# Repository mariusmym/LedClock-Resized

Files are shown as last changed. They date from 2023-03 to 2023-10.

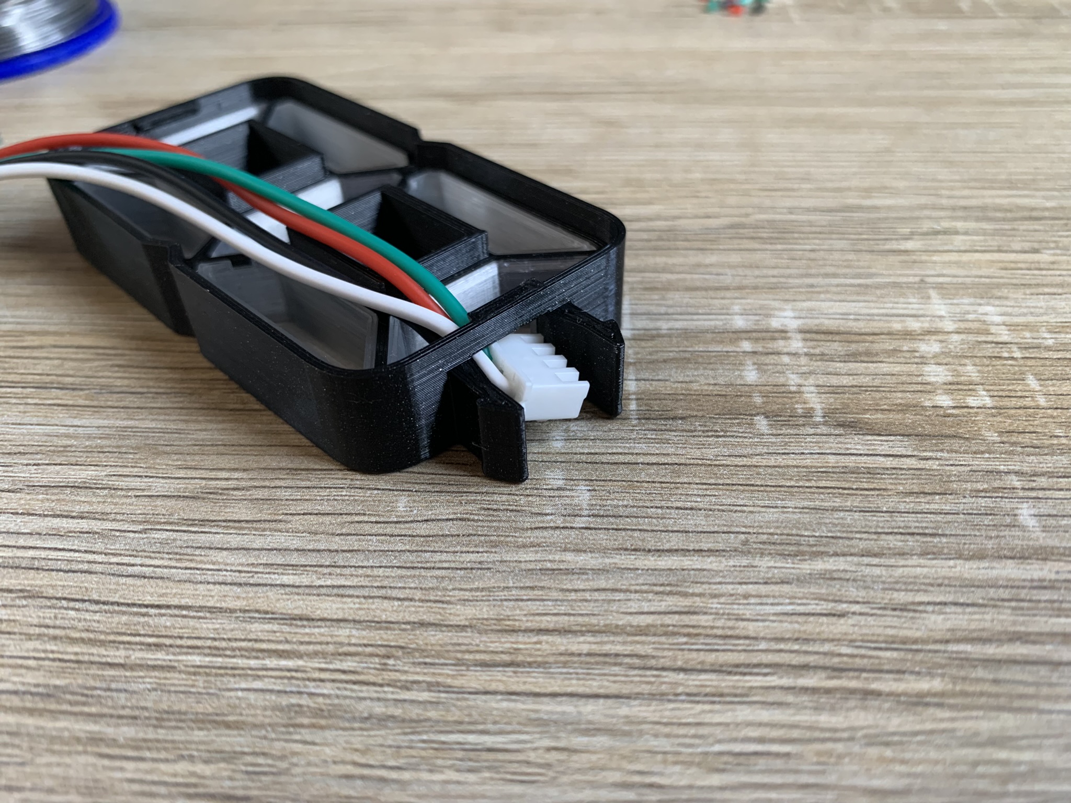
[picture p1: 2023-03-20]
LedClock-Resized2-40x66mm/Images/IMG_2581.jpeg

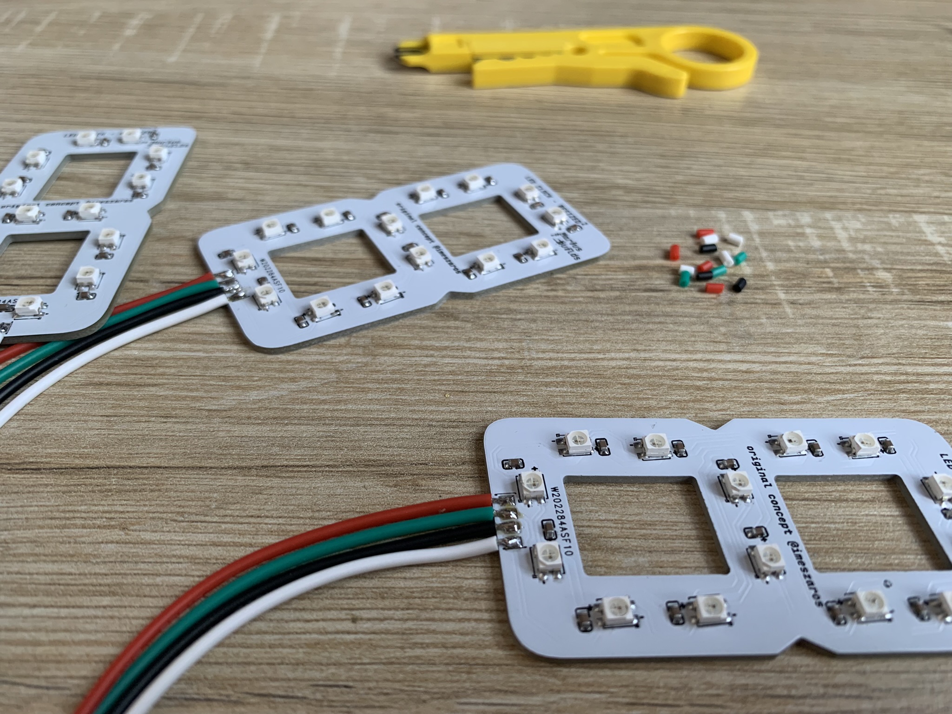
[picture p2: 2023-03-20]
LedClock-Resized2-40x66mm/Images/IMG_2576.jpeg

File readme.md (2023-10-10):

LED Clock

<p align="center">
  
  
  
  
</p>

# LedClock-Resized

## About

As its name tells, this is a resized and an easier to make/print version of [ledclock project](https://github.com/imeszaros/ledclock), powered by [WLED](https://github.com/Aircoookie/WLED). 

**There are TWO resized dimensions available:** 
  1. **52x92mm digits version** : [see folder](https://github.com/mariusmym/LedClock-Resized/tree/master/LedClock_Resized)
  2. **40x66mm digits version** : [see folder](https://github.com/mariusmym/LedClock-Resized/tree/master/LedClock-Resized2-40x66mm)
  
**Keep in mind that dimensions mentioned above represents only the height of the PCB digits. The base is not included. Height of the base is the same.**
  
IMG_3209 copy

This fork is intended just to share the Gerbers and 3D files I used for this remix. If you need more detailed informations, please read descriptions and assembly guide from the [original repository](https://github.com/imeszaros/ledclock).
[imeszaros](https://github.com/imeszaros) did an oustanding job in providing all the explanations required. 

## Main differences

- all PCBs are under 100mm height so you can order them for like $5 + shipping from [PCBWay.com](https://www.pcbway.com/) .
You can also order them directly from [my PCBWay profile](https://www.pcbway.com/project/member/?bmbno=1D9FACD8-0C52-4C) you can download the gerber files and send them to your manufacturer. 
- 3D printed parts can be printed on smaller printers because the base is split in half (you have to assemble it with some M3 screws and nuts). I printed my parts on an Ender3 V2, so I guess anyone can print them.
- 3D printed parts can be printed without supports. Please check 3mf folder to see orientation if you can't figure it out.
- controller board, led 7segments and dots now uses only 0805 SMD components for easier soldering. I don't have a reflow hot-plate so I made the assembly by hand.
- controller board now uses an **ESP32 D1 Mini** [link for reference](https://www.aliexpress.com/item/1005003746817278.html) for more convenience. By using an embedded ESP32 you will have to overcomplicate the board. Another reason for using a dedicated ESP32 D1 Mini is because some of the components required in the original design are impossible to solder by hand (CP2102). I
f you want, **you can use the original controller board design**, is fully compatible with **LedClock-Resized**.

## Firmware

Firmware is provided by the awesome work of [imeszaros](https://github.com/imeszaros). 
Just connect the ESP32 Mini onto the computer (be sure you have drivers installed for your board USB-TTL chip) and use [this tool](https://imeszaros.github.io/ledclock/) for initial flash. Then plug the ESP32 board it into the main controller board.

## Assembly

Assembly of this project is pretty straightforward: 
- order the PCBs and solder them

28373dad-76af-430c-a674-46bc3df38653



IMG_2576s

- print the 3D required parts and assemble them (use 4 x M3x20mm screws and nuts to join the base of the 52x92mm version)

IMG_3756s

d58b3460-f934-42f0-a672-9b96344d7cfe

- flash the firmware on the ESP32 Mini and then connect it to the controller board.

IMG_4004s

- join the PCBs with the 3D printed parts

IMG_2581s

d932719f-d477-4b1a-8fd8-3f6773710fba

IMG_1876s

IMG_4681ss

- **provide 5V 2A power supply with  2.5mm x 5.85mm barrel jack connector.** 
- make your settings in the WLED APP. Use [this guide](https://github.com/imeszaros/ledclock/blob/master/ledclock/users-guide.md) if you're not familiarized with WLED App.

## ENJOY !



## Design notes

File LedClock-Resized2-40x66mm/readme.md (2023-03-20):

## LedClock-Resized 40x66 mm version

### Files for the 40x66mm digits version of LedClock-Resized. Please see folders above.

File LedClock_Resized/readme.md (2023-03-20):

## LedClock-Resized 52x92 mm version

### Files for the 52x92mm digits version of LedClock-Resized. Please see folders above.

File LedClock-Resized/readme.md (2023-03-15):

# LedClock-Resized

## About

As its name tells, this is a resized and an easier to make version of ledclock project.

Main differences are:

- all PCBs are under 100mm height so you can order them for like $5 + shipping from [PCBWay.com](https://www.pcbway.com/) .
You can also order them directly from [my PCBWay profile](https://www.pcbway.com/project/member/?bmbno=1D9FACD8-0C52-4C) you can download the gerber files and send them to your manufacturer. 
- 3D printed parts can be printed on smaller printers because the base is split in half (you have to assemble it with some M3 screws and nuts). I printed my parts on an Ender3 V2, so I guess anyone can print them.
- 3D printed parts can be printed without supports. Please check 3mf folder to see orientation if you can't figure it out.
- controller board, led 7segments and dots now uses only 0805 SMD components for easier soldering. I don't have a reflow hot-plate so I made the assembly by hand.
- controller board now uses an **ESP32 D1 Mini** [link for reference](https://www.aliexpress.com/item/1005003746817278.html) for more convenience. By using an embedded ESP32 you will have to overcomplicate the board. Another reason for using a dedicated ESP32 D1 Mini is because some of the components required in the original design are impossible to solder by hand (CP2102). 

## Firmware

Firmware is provided by the awesome work of [@imeszaros](https://github.com/imeszaros). 
Just connect the ESP32 Mini onto the computer (be sure you have drivers installed for CHxxxx or CPxxxx chip) and use [this awesome tool](https://imeszaros.github.io/ledclock/) for initial flash. Then plug the ESP32 it into the main controller board

## Assembly

Assembly of this project is pretty straightforward: 
- order the PCBs and solder them

28373dad-76af-430c-a674-46bc3df38653



- print the 3D required parts and assemble them (use 4 x M3x20mm screws and nuts to join the base)

IMG_3756s

d58b3460-f934-42f0-a672-9b96344d7cfe

- flash the firmware on the ESP32 Mini and then connect it to the controller board.

IMG_4004s

- join the PCBs with the 3D printed parts

d932719f-d477-4b1a-8fd8-3f6773710fba

IMG_1876s

- **provide 5V 2A power supply with  2.5mm x 5.85mm barrel jack connector.** 
- make your settings in the WLED APP. Use [this guide](https://github.com/imeszaros/ledclock/blob/master/ledclock/users-guide.md) if you're not familiarized with WLED App.

## ENJOY !

34732020s

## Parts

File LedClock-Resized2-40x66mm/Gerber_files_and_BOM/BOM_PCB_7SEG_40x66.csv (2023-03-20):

ID | Name | Designator | Footprint | Quantity | Manufacturer Part | Manufacturer | Supplier | Supplier Part | Price
1 | WS2812B-MINI | 1,2,3,4,5,6,7,8,9,10,11,12,13,14 | LED-SMD_4P-L3.5-W3.5-TL_WS2812B | 14 | WS2812B-Mini | worldsemi | LCSC | C527089 | 0.016
2 | 100nF | C1,C2,C3,C4,C5,C6,C7,C8,C9,C10,C11,C12,C13,C14 | C0603 | 14 | C0603C104K5RACAUTO | KEMET(基美) | LCSC | C129621 | 0.002
3 | HDR-M-2.54_1x4 | J1 | H1X4_SMD_SMALL | 1 |  |  | LCSC | C124378 | 0.007

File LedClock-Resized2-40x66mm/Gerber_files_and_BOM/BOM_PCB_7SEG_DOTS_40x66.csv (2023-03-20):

ID | Name | Designator | Footprint | Quantity | Manufacturer Part | Manufacturer | Supplier | Supplier Part | Price
1 | 100nF | C1,C2 | C0603 | 2 | C0603C104K5RACAUTO | KEMET(基美) | LCSC | C129621 | 0.002
2 | WS2812B-MINI | 1,2 | LED-SMD_4P-L3.5-W3.5-TL_WS2812B | 2 | WS2812B-Mini | worldsemi | LCSC | C527089 | 0.016
3 | HDR-M-2.54_1x4 | J1 | H1X4_SMD_SMALL | 1 |  |  | LCSC | C124378 | 0.007

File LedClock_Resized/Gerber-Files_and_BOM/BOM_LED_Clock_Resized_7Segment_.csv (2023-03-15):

ID | Name | Designator | Footprint | Quantity | Manufacturer Part | Manufacturer | Supplier | Supplier Part | Price
1 | HDR-M-2.54_1x4 | J1 | H2X2_SMD | 1 |  |  | LCSC | C124378 | 0.007
2 | WS2812B | U1,U2,U3,U4,U5,U6,U7,U8,U9,U10,U11,U12,U13,U14 | LED-SMD_4P-L5.0-W5.0-TL | 14 | WS2812B | Worldsemi | LCSC | C114585
3 | 100nF | C1,C2,C3,C4,C5,C6,C7,C8,C9,C10,C11,C12,C13,C14 | C0805 | 14 | CC0805KRX7R9BB104 | YAGEO(国巨) | LCSC | C49678 | 0.001

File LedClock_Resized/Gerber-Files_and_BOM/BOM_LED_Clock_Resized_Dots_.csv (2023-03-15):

ID | Name | Designator | Footprint | Quantity | Manufacturer Part | Manufacturer | Supplier | Supplier Part | Price
1 | 100nF | C1,C2 | C0805 | 2 | CC0805KRX7R9BB104 | YAGEO(国巨) | LCSC | C49678 | 0.001
2 | WS2812B | U2,U1 | LED-SMD_4P-L5.0-W5.0-TL | 2 | WS2812B | Worldsemi | LCSC | C114585
3 | HDR-M-2.54_1x4 | J1 | H2X2_SMD | 1 |  |  | LCSC | C124378 | 0.007

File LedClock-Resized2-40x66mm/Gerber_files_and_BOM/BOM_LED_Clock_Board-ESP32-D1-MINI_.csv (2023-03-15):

ID | Name | Designator | Footprint | Quantity | Manufacturer Part | Manufacturer | Supplier | Supplier Part | Price
1 | 50kΩ | R4 | RES-ADJ-SMD_3314G-1-103E | 1 | 3314G-1-503E | BOURNS | LCSC | C719184 | 0.085
2 | 470uF | C1 | CAP-SMD_BD6.3-L6.6-W6.6-FD | 1 | RVT0J471M0607 | HONOR(荣誉) | LCSC | C3354 | 0.008
3 | HX25003-4WAP | CN3,CN1,CN2,CN4,CN5 | CONN-TH_4P-P2.50_HX25003-4WAP | 5 | HX25003-4WAP | HX(Zhejiang Yueqing Hongxing Elec) | LCSC | C442328 | 0.004
4 | 100 | R1 | R0805 | 1 | AC0805FR-07100RL | YAGEO(国巨) | LCSC | C138274 | 0.001
5 | 10K | R2,R3 | R0805 | 2 | AC0805FR-0710KL | YAGEO(国巨) | LCSC | C140868 | 0.001
6 | BUZZER | SG1 | DIP-BUZZER-12X9.5 | 1
7 | DC-005I-5A-2.5 | DC1 | DC-IN-TH_DC-005I-5A-2.5 | 1 | DC-005I-5A-2.5 | XKB Connectivity(中国星坤) | LCSC | C2689704 | 0.083
8 | TEPT5700 | Q3 | TEPT5700 | 1 | TEPT5700 | VISHAY | LCSC | C141763 | 0.089
9 | BSS138 | Q4 | SOT-23-3_L2.9-W1.3-P1.90-LS2.4-BR | 1 | BSS138 | CJ | LCSC | C78284 | 0.004

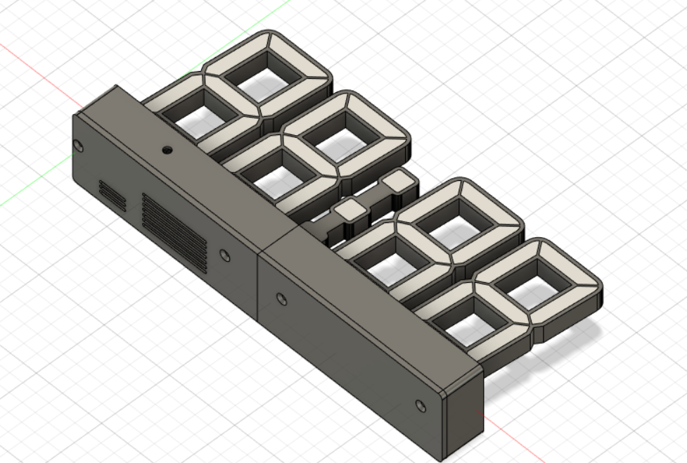
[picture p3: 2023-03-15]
LedClock_Resized/CAD files/Led-Clock-Resized(2PartsBase)-f3z.png

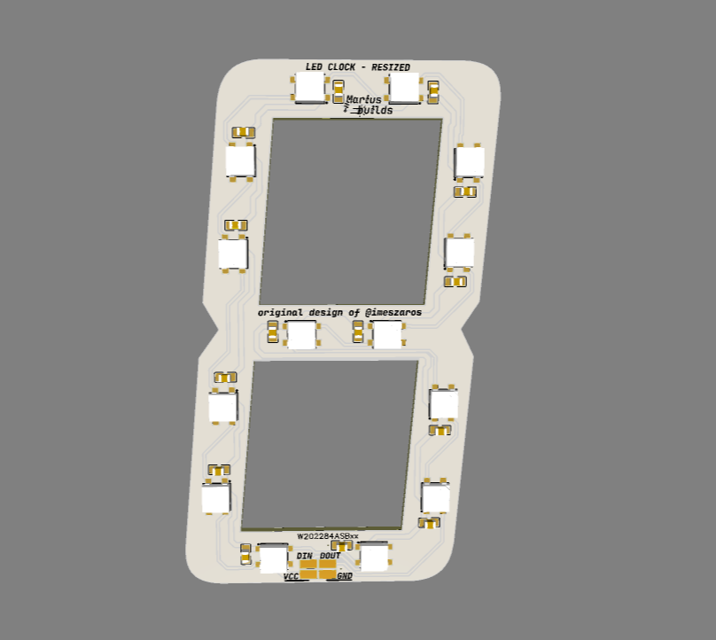
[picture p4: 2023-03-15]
LedClock_Resized/Gerber-Files_and_BOM/LED_Clock_Resized_7Segment_1.png

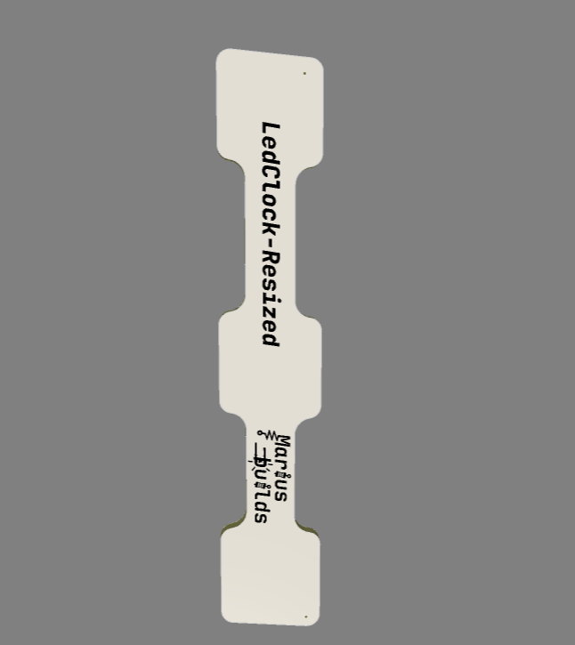
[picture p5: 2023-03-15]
LedClock_Resized/Gerber-Files_and_BOM/LED_Clock_Resized_Dots_2.png

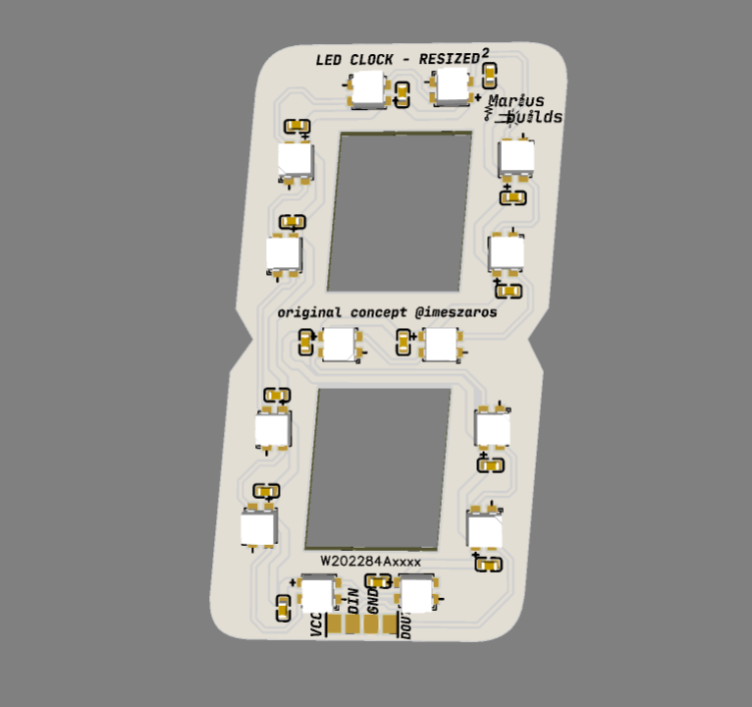
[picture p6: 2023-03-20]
LedClock-Resized2-40x66mm/Gerber_files_and_BOM/7SEG_40X66_1.png

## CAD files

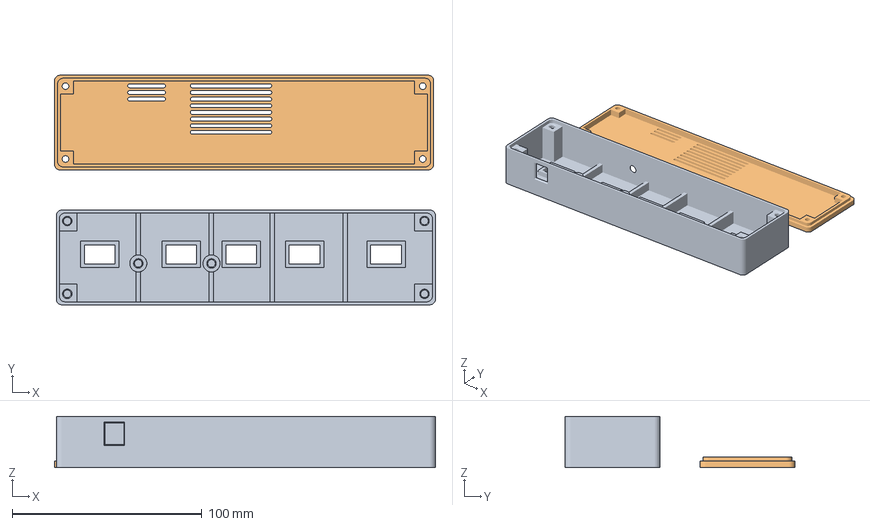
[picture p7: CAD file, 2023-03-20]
LedClock-Resized2-40x66mm/3D_printing_files/3mf_files/BASE_Body&Lid.3mf
200.9 x 121.1 x 27.0 mm
BaseBody.stl
LidBody.stl

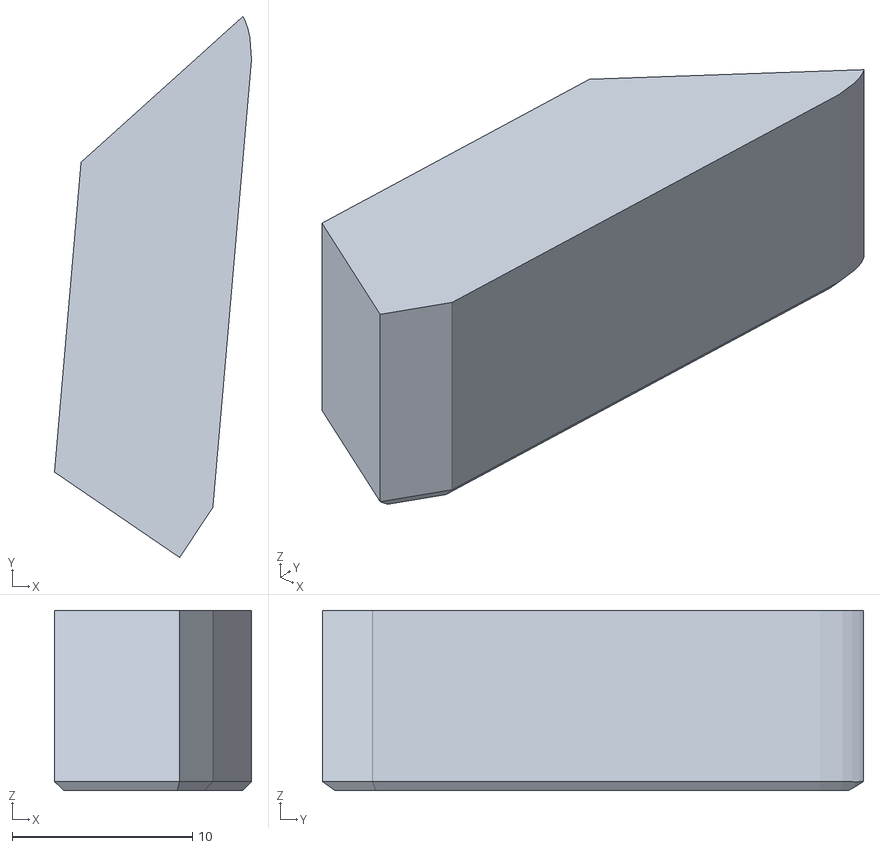
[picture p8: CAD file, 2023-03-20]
LedClock-Resized2-40x66mm/3D_printing_files/STL_files/7SEG_40x66/SegCovBody3.stl
10.9 x 30.0 x 10.0

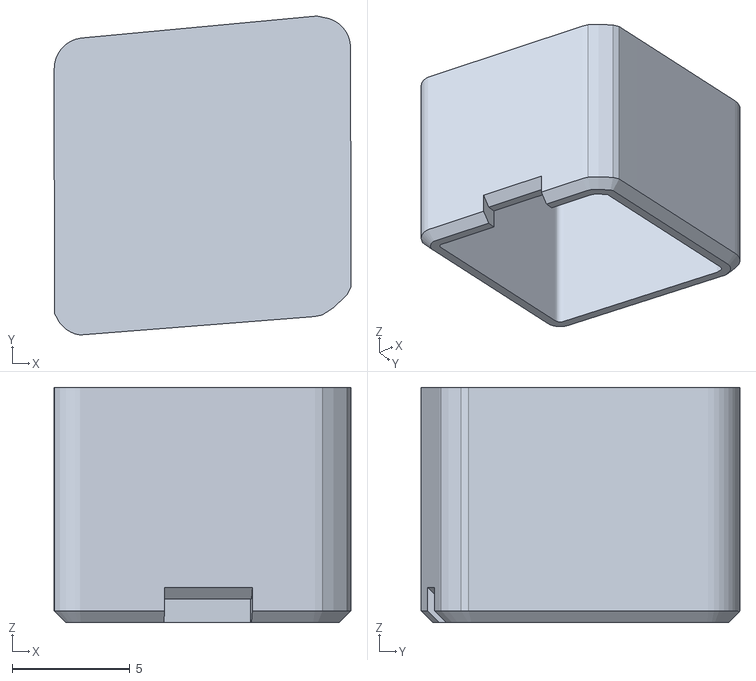
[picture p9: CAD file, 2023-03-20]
LedClock-Resized2-40x66mm/3D_printing_files/STL_files/7SEG_DOTS_40x66/DotsCover1.stl
12.6 x 13.6 x 10.0

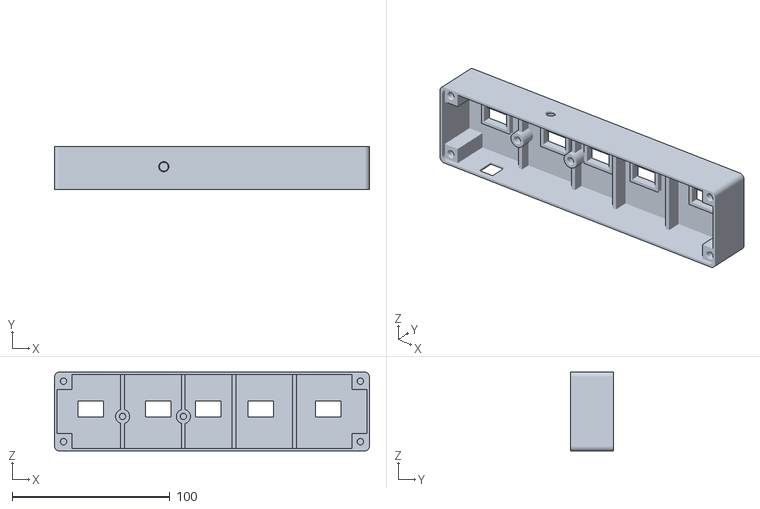
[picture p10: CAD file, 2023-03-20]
LedClock-Resized2-40x66mm/3D_printing_files/STL_files/BASE_FOR_40x66/BaseBody.stl
200.0 x 27.0 x 50.0

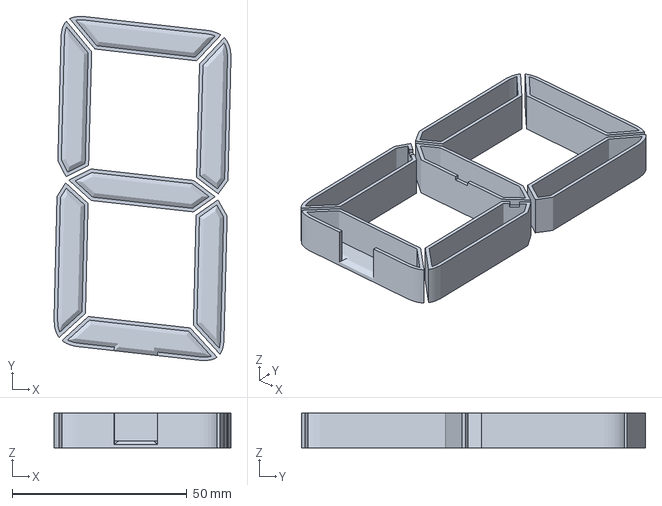
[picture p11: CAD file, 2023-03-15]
LedClock_Resized/3D-print/3mf-files/CE3_SegmentCovers-ALL.3mf
50.6 x 98.4 x 10.0 mm

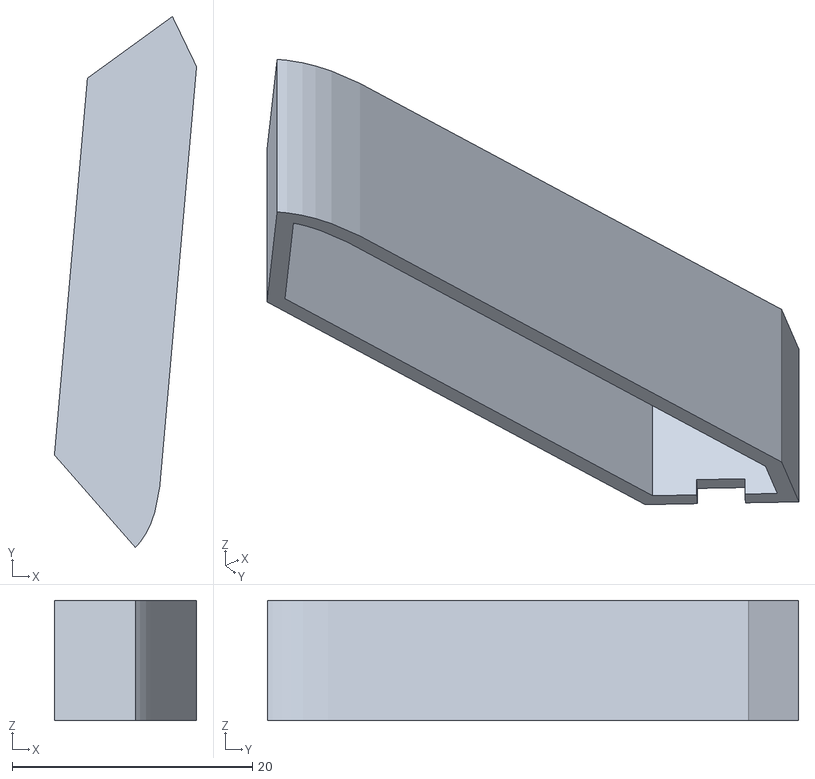
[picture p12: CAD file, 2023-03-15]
LedClock_Resized/3D-print/stl-files/SegmentCover-BottomRight.stl
11.8 x 44.2 x 10.0

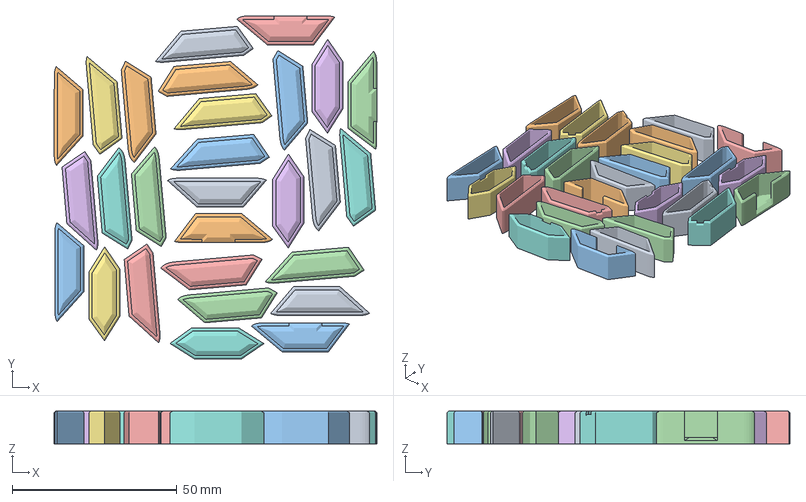
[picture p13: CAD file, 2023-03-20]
LedClock-Resized2-40x66mm/3D_printing_files/3mf_files/7SEG_LED_COVERS.3mf
98.0 x 104.2 x 10.0 mm
SegCovBody1.stl
SegCovBody2.stl
SegCovBody3.stl
SegCovBody4.stl
SegCovBody5.stl
SegCovBody6.stl
SegCovBody7.stl
SegCovBody5.stl(1)
SegCovBody5.stl(2)
SegCovBody5.stl(3)
SegCovBody2.stl(1)
SegCovBody2.stl(2)
SegCovBody2.stl(3)
SegCovBody6.stl(1)
SegCovBody6.stl(2)
SegCovBody6.stl(3)
SegCovBody1.stl(1)
SegCovBody1.stl(2)
SegCovBody1.stl(3)
SegCovBody3.stl(1)
SegCovBody3.stl(2)
SegCovBody3.stl(3)
SegCovBody7.stl(1)
SegCovBody7.stl(2)
SegCovBody7.stl(3)
SegCovBody4.stl(1)
SegCovBody4.stl(2)
SegCovBody4.stl(3)

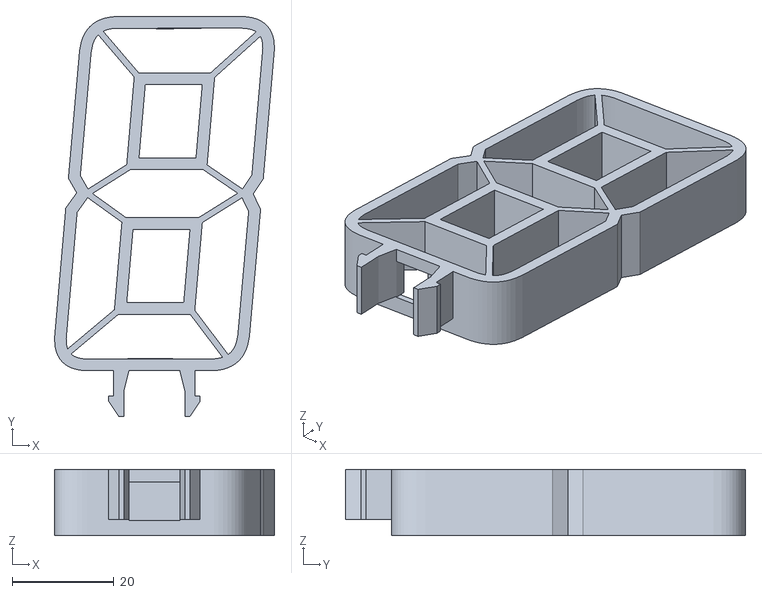
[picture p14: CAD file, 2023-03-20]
LedClock-Resized2-40x66mm/3D_printing_files/STL_files/7SEG_40x66/Case.stl
43.2 x 78.6 x 13.0

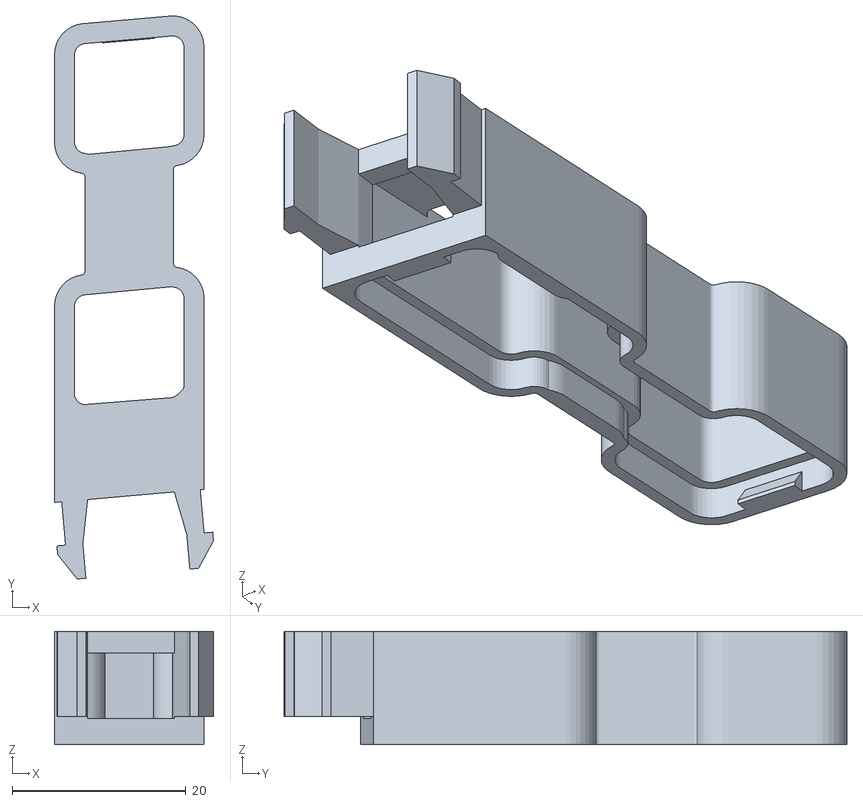
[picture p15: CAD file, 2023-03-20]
LedClock-Resized2-40x66mm/3D_printing_files/STL_files/7SEG_DOTS_40x66/DotsCase.stl
18.3 x 64.8 x 13.0

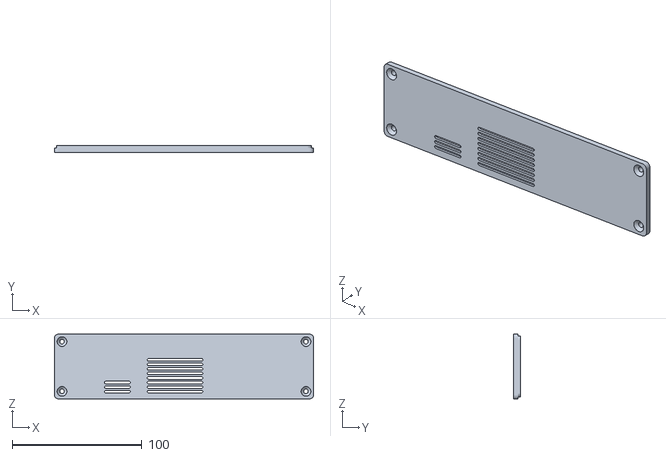
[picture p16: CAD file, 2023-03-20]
LedClock-Resized2-40x66mm/3D_printing_files/STL_files/BASE_FOR_40x66/LidBody.stl
200.0 x 5.60 x 50.0

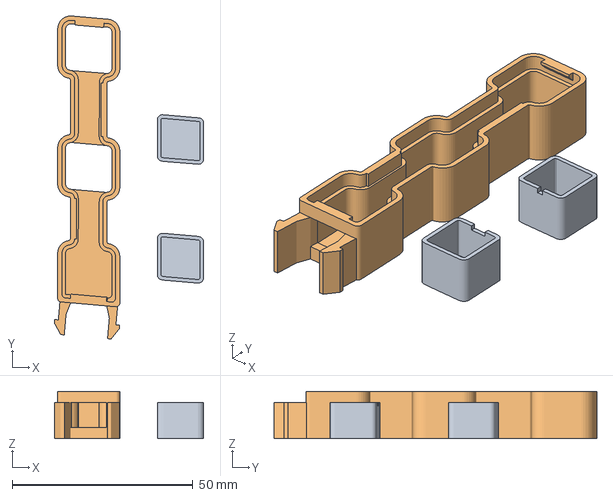
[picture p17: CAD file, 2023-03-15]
LedClock_Resized/3D-print/3mf-files/Dots-LedCover-and-CaseALL.3mf
41.3 x 89.3 x 13.0 mm
Dots-LedCover-ALL.stl
Dots-Case.stl

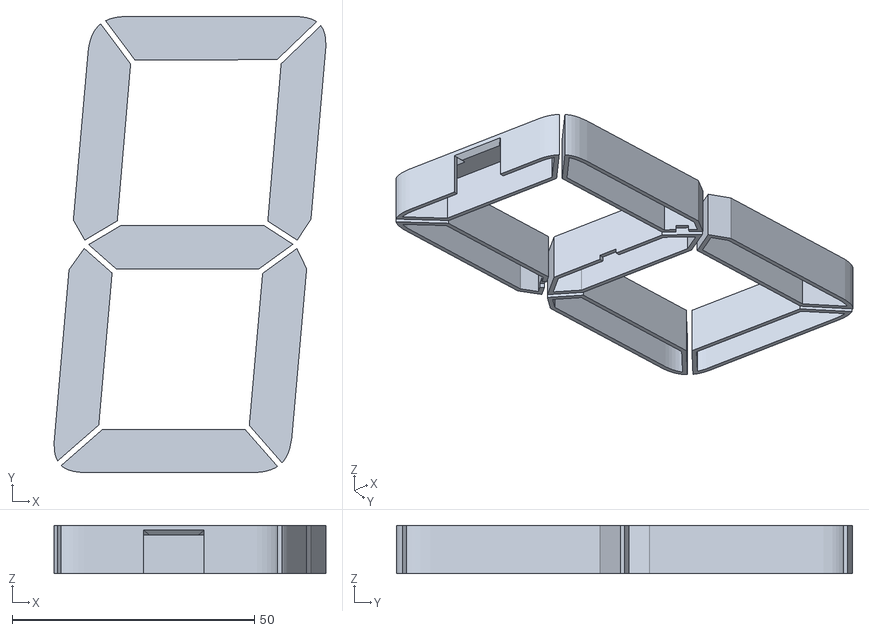
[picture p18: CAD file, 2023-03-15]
LedClock_Resized/3D-print/stl-files/SegmentCovers-ALL.stl
56.1 x 94.1 x 10.0

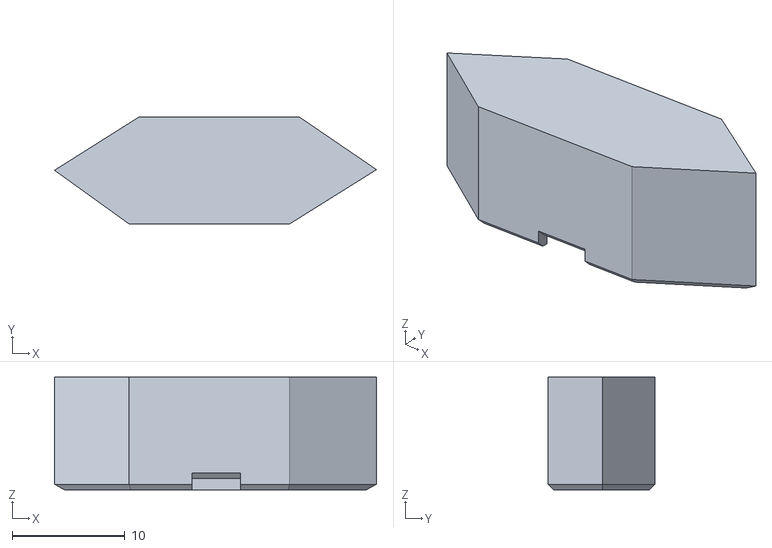
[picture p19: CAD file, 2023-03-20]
LedClock-Resized2-40x66mm/3D_printing_files/STL_files/7SEG_40x66/SegCovBody6.stl
28.5 x 9.47 x 10.0

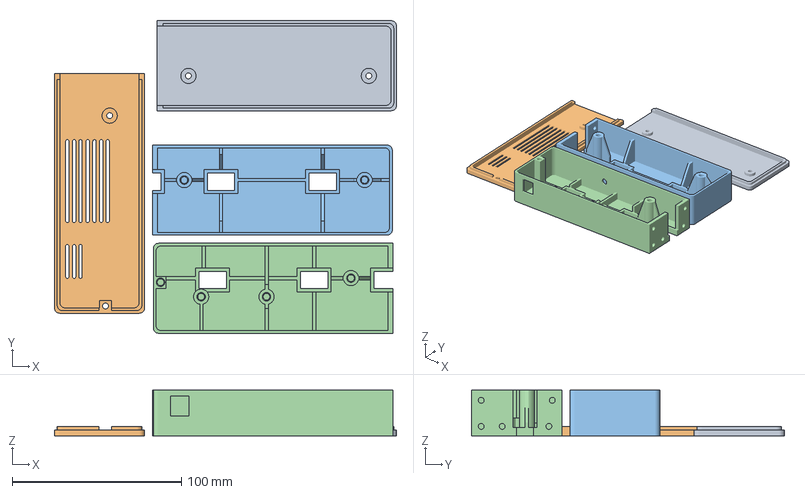
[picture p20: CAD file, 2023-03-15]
LedClock_Resized/3D-print/3mf-files/All-Base-Parts.3mf
202.1 x 184.7 x 27.0 mm
BaseLidB.stl
BaseLidA.stl
BaseBodyB.stl
BaseBodyA.stl

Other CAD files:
LedClock-Resized2-40x66mm/3D_printing_files/3mf_files/7SEG_DOTS_CASE.3mf
LedClock-Resized2-40x66mm/3D_printing_files/STL_files/7SEG_DOTS_40x66/DotsCover2.stl
LedClock_Resized/3D-print/stl-files/SegmentCover-TopRight.stl
LedClock-Resized2-40x66mm/3D_printing_files/3mf_files/7SEG_DOTS_LED_Covers.3mf
LedClock-Resized2-40x66mm/3D_printing_files/3mf_files/7SEG_CASE_40x66.3mf
LedClock-Resized2-40x66mm/3D_printing_files/STL_files/7SEG_40x66/SegCovBody1.stl
LedClock-Resized2-40x66mm/3D_printing_files/STL_files/7SEG_40x66/SegCovBody2.stl
LedClock-Resized2-40x66mm/3D_printing_files/STL_files/7SEG_40x66/SegCovBody4.stl
LedClock-Resized2-40x66mm/3D_printing_files/STL_files/7SEG_40x66/SegCovBody5.stl
LedClock-Resized2-40x66mm/3D_printing_files/STL_files/7SEG_40x66/SegCovBody7.stl
LedClock_Resized/3D-print/3mf-files/CE3_SegmentCase.3mf
LedClock_Resized/3D-print/stl-files/BaseBodyA.stl
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
